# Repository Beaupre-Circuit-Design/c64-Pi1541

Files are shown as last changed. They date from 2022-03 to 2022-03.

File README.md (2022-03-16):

# Pi1541-Hat

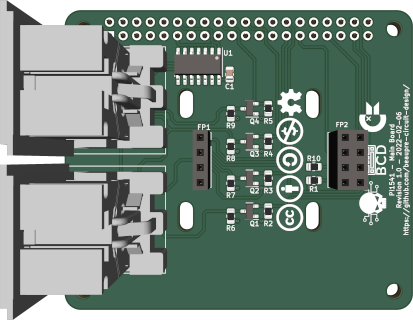
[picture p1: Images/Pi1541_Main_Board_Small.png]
MegaCart-64 Rendering

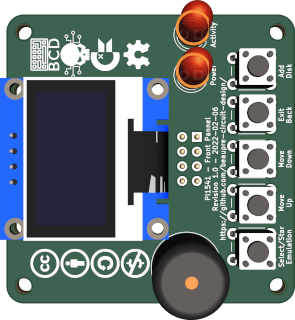
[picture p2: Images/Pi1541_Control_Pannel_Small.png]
MegaCart-64 PCB


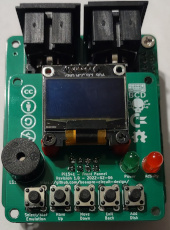
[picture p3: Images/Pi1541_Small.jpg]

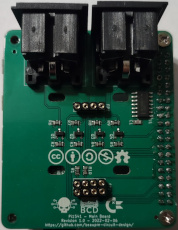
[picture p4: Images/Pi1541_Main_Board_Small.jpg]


# Introduction

An open-source Raspberry-Pi Hat for the [Pi1541 firmware](https://cbm-pi1541.firebaseapp.com/). The Hat is divided into two small PCB, the mainboard with the connectors and support logic, and the control board.  They can be assembled together in one unit, or separatly to fit your choice of enclosure.

# Compatibility

The Hat should be compatible with all 40-pins Raspberry Pi supported by the Pi1541 project. That said, i've only tested it with a Raspberry-Pi Zero 2W.

# Configuration

## Rasperry-Pi Zero/2/3.

Follow the instructions of the official firmware. Once your SD created, change the following lines in the file 'options.txt':

    // Uncomment splitIECLines by uncommenting this line. .
	splitIECLines = 1
	// Enable the LCD Display by uncommenting this line. 
	LCDName = ssd1306_128x64
	// Enable KeyboardBrowseLCDScreen by uncommenting theses lines.
	KeyboardBrowseLCDScreen = 1
	i2cBusMaster = 0
	// Disabling GraphIEC for more stability and compatibility with fastloaders by commenting this line.
	//GraphIEC = 1

## Rasperry-Pi Zero 2W.

Follow the instructions of the [c64-Pi1541-Zero2W-Firmware]([Firmware/](https://github.com/Beaupre-Circuit-Design/c64-Pi1541-Zero2W-Firmware)) Github repository.

# Components and assembly

[Gerbers files](Gerbers/) and SMD assembly files are available for uploading to your prefered manufacturer (I personnally use JLCPCB).  The mainboard use SMT parts (except for the headers) while the control board use through-hole components. Refer to the [Bill of Materials](Pi1541-BOM.xlsx) Excel sheet for a complete list of needed components.

# Licence

This work is licensed under the Creative Commons Attribution-NonCommercial-ShareAlike 4.0 International License. To view a copy of this license, visit http://creativecommons.org/licenses/by-nc-sa/4.0/ or send a letter to Creative Commons, PO Box 1866, Mountain View, CA 94042, USA.

# Revision History

|Revision  |Description |
|:---:|---|
|1.0 |Initial prototype |

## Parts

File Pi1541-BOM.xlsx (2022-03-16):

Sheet: Main Board
Ref | Value | Footprint | Datasheet | Manufacturer | Mfr.Part | LCSC | Digikey | AliExpress | Notes
C1 | 100nF | Capacitor_SMD:C_0805_2012Metric | https://datasheet.lcsc.com/lcsc/1810241824_Samsung-Electro-Mechanics-CL21C101JBANNNC_C1790.pdf | Samsung Electro-Mechanics | CL21C101JBANNNC | C1790 | 1276-1014-1-ND
FP1 | Conn_01x04_Counter_Clockwise | Connector_PinSocket_2.54mm:PinSocket_1x04_P2.54mm_Vertical | https://datasheet.lcsc.com/lcsc/2103011236_BOOMELE-Boom-Precision-Elec-C2718488_C2718488.pdf | Boom Precision Elec | C2718488 | C2718488 | S7037-ND
FP2 | Conn_02x04_Counter_Clockwise | Connector_PinSocket_2.54mm:PinSocket_2x04_P2.54mm_Vertical | https://datasheet.lcsc.com/lcsc/1810221610_Ckmtw-Shenzhen-Cankemeng-B-2200S08P-B120_C124422.pdf | Shenzhen Cankemeng | B-2200S08P-B120 | C124422 | S7107-ND
J1 | DIN-45322 | DIN_45322:DIN_45322 | https://www.aliexpress.com/item/1005001265863686.html | AliExpress |  |  |  | 1005001265863680
J2 | DIN-45322 | DIN_45322:DIN_45322 | https://www.aliexpress.com/item/1005001265863686.html | AliExpress |  |  |  | 1005001265863680
P1 | Conn_02x20_Odd_Even | Connector_PinSocket_2.54mm:PinSocket_2x20_P2.54mm_Vertical | https://datasheet.lcsc.com/lcsc/1811111512_BOOMELE-Boom-Precision-Elec-C50982_C50982.pdf | Boom Precision Elec | C50982 | C50982 | S7123-ND
Q1 | BSS138 | Package_TO_SOT_SMD:SOT-23 | https://datasheet.lcsc.com/lcsc/1811101310_Shikues-BSS138_C112239.pdf | Shikues | BSS138 | C112239 | BSS138CT-ND
Q2 | BSS138 | Package_TO_SOT_SMD:SOT-23 | https://datasheet.lcsc.com/lcsc/1811101310_Shikues-BSS138_C112239.pdf | Shikues | BSS138 | C112239 | BSS138CT-ND
Q3 | BSS138 | Package_TO_SOT_SMD:SOT-23 | https://datasheet.lcsc.com/lcsc/1811101310_Shikues-BSS138_C112239.pdf | Shikues | BSS138 | C112239 | BSS138CT-ND
Q4 | BSS138 | Package_TO_SOT_SMD:SOT-23 | https://datasheet.lcsc.com/lcsc/1811101310_Shikues-BSS138_C112239.pdf | Shikues | BSS138 | C112239 | BSS138CT-ND
R1 | 100Ω | Resistor_SMD:R_0805_2012Metric | https://datasheet.lcsc.com/lcsc/2110251730_UNI-ROYAL-Uniroyal-Elec-0805W8F1000T5E_C17408.pdf | UNI-ROYAL(Uniroyal Elec) | 0805W8F1000T5E | C17408 | 311-100CRCT-ND
R2 | 1KΩ | Resistor_SMD:R_0805_2012Metric | https://datasheet.lcsc.com/lcsc/2110251730_UNI-ROYAL-Uniroyal-Elec-0805W8F1001T5E_C17513.pdf | UNI-ROYAL(Uniroyal Elec) | 0805W8F1001T5E | C17513 | 311-1.00KCRCT-ND
R3 | 1KΩ | Resistor_SMD:R_0805_2012Metric | https://datasheet.lcsc.com/lcsc/2110251730_UNI-ROYAL-Uniroyal-Elec-0805W8F1001T5E_C17513.pdf | UNI-ROYAL(Uniroyal Elec) | 0805W8F1001T5E | C17513 | 311-1.00KCRCT-ND
R4 | 1KΩ | Resistor_SMD:R_0805_2012Metric | https://datasheet.lcsc.com/lcsc/2110251730_UNI-ROYAL-Uniroyal-Elec-0805W8F1001T5E_C17513.pdf | UNI-ROYAL(Uniroyal Elec) | 0805W8F1001T5E | C17513 | 311-1.00KCRCT-ND
R5 | 1KΩ | Resistor_SMD:R_0805_2012Metric | https://datasheet.lcsc.com/lcsc/2110251730_UNI-ROYAL-Uniroyal-Elec-0805W8F1001T5E_C17513.pdf | UNI-ROYAL(Uniroyal Elec) | 0805W8F1001T5E | C17513 | 311-1.00KCRCT-ND
R6 | 1KΩ | Resistor_SMD:R_0805_2012Metric | https://datasheet.lcsc.com/lcsc/2110251730_UNI-ROYAL-Uniroyal-Elec-0805W8F1001T5E_C17513.pdf | UNI-ROYAL(Uniroyal Elec) | 0805W8F1001T5E | C17513 | 311-1.00KCRCT-ND
R7 | 1KΩ | Resistor_SMD:R_0805_2012Metric | https://datasheet.lcsc.com/lcsc/2110251730_UNI-ROYAL-Uniroyal-Elec-0805W8F1001T5E_C17513.pdf | UNI-ROYAL(Uniroyal Elec) | 0805W8F1001T5E | C17513 | 311-1.00KCRCT-ND
R8 | 1KΩ | Resistor_SMD:R_0805_2012Metric | https://datasheet.lcsc.com/lcsc/2110251730_UNI-ROYAL-Uniroyal-Elec-0805W8F1001T5E_C17513.pdf | UNI-ROYAL(Uniroyal Elec) | 0805W8F1001T5E | C17513 | 311-1.00KCRCT-ND
R9 | 1KΩ | Resistor_SMD:R_0805_2012Metric | https://datasheet.lcsc.com/lcsc/2110251730_UNI-ROYAL-Uniroyal-Elec-0805W8F1001T5E_C17513.pdf | UNI-ROYAL(Uniroyal Elec) | 0805W8F1001T5E | C17513 | 311-1.00KCRCT-ND
R10 | 100Ω | Resistor_SMD:R_0805_2012Metric | https://datasheet.lcsc.com/lcsc/2110251730_UNI-ROYAL-Uniroyal-Elec-0805W8F1000T5E_C17408.pdf | UNI-ROYAL(Uniroyal Elec) | 0805W8F1000T5E | C17408 | 311-100CRCT-ND
U1 | 74LS06 | Package_SO:SOIC-14_3.9x8.7mm_P1.27mm | https://datasheet.lcsc.com/lcsc/1810151621_Texas-Instruments-SN74LS06DR_C113682.pdf | Texas Instruments | SN74LS06DR | C113682 | 296-14876-1-ND

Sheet: Front Pannel
Ref | Value | Footprint | Datasheet | Manufacturer | Mfr.Part | LCSC | Digikey | AliExpress | Notes
D1 | RED LED | LED_THT:LED_D5.0mm | https://datasheet.lcsc.com/lcsc/1810271709_Everlight-Elec-333-2SURD-S530-A3_C87271.pdf | Everlight Elec | 333-2SURD/S530-A3 | C87271 | 1125-1188-ND
D2 | GREEN LED | LED_THT:LED_D5.0mm | https://datasheet.lcsc.com/lcsc/1810271709_Everlight-Elec-333-2SURD-S530-A3_C87271.pdf | Everlight Elec | 333-2SYGD/S530-E2 | C88163 | 1125-1184-ND
DS1 | 128x64_I2C_OLED_Display | Display_I2C_OLED:128x64 I2C OLED Display | https://www.aliexpress.com/item/1005001621806398.html | AliExpress |  |  |  | 1005001621806390
FP1 | Conn_01x04_Counter_Clockwise | Connector_PinHeader_2.54mm:PinHeader_1x04_P2.54mm_Vertical | https://datasheet.lcsc.com/lcsc/1811151421_Ckmtw-Shenzhen-Cankemeng-B-2100S04P-A110_C124378.pdf | Shenzhen Cankemeng | B-2100S04P-A110 | C124378 | 609-3305-ND
FP2 | Conn_02x04_Counter_Clockwise | Connector_PinHeader_2.54mm:PinHeader_2x04_P2.54mm_Vertical | https://datasheet.lcsc.com/lcsc/1811151421_Ckmtw-Shenzhen-Cankemeng-B-2100S08P-B110_C124386.pdf | Shenzhen Cankemeng | B-2100S08P-B110 | C124386 | 609-3391-ND
LS1 | YHE12-03 | Buzzer_Beeper:Buzzer_12x9.5RM7.6 | https://www.aliexpress.com/item/33005016402.html | AliExpress |  |  |  | 33005016402
SW1 | SW_Push | Button_Switch_THT:SW_PUSH_6mm | https://www.aliexpress.com/item/32912263133.html | AliExpress |  |  |  | 32912263133
SW2 | SW_Push | Button_Switch_THT:SW_PUSH_6mm | https://www.aliexpress.com/item/32912263133.html | AliExpress |  |  |  | 32912263133
SW3 | SW_Push | Button_Switch_THT:SW_PUSH_6mm | https://www.aliexpress.com/item/32912263133.html | AliExpress |  |  |  | 32912263133
SW4 | SW_Push | Button_Switch_THT:SW_PUSH_6mm | https://www.aliexpress.com/item/32912263133.html | AliExpress |  |  |  | 32912263133
SW5 | SW_Push | Button_Switch_THT:SW_PUSH_6mm | https://www.aliexpress.com/item/32912263133.html | AliExpress |  |  |  | 32912263133

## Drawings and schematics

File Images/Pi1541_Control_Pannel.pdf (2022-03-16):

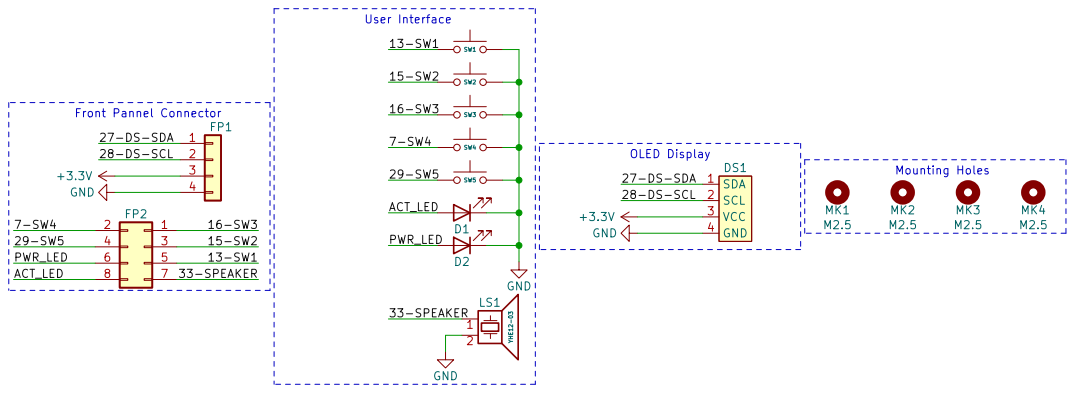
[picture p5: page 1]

OLED Display Front Pannel Connector
27-DS-SDA
28-DS-SCL

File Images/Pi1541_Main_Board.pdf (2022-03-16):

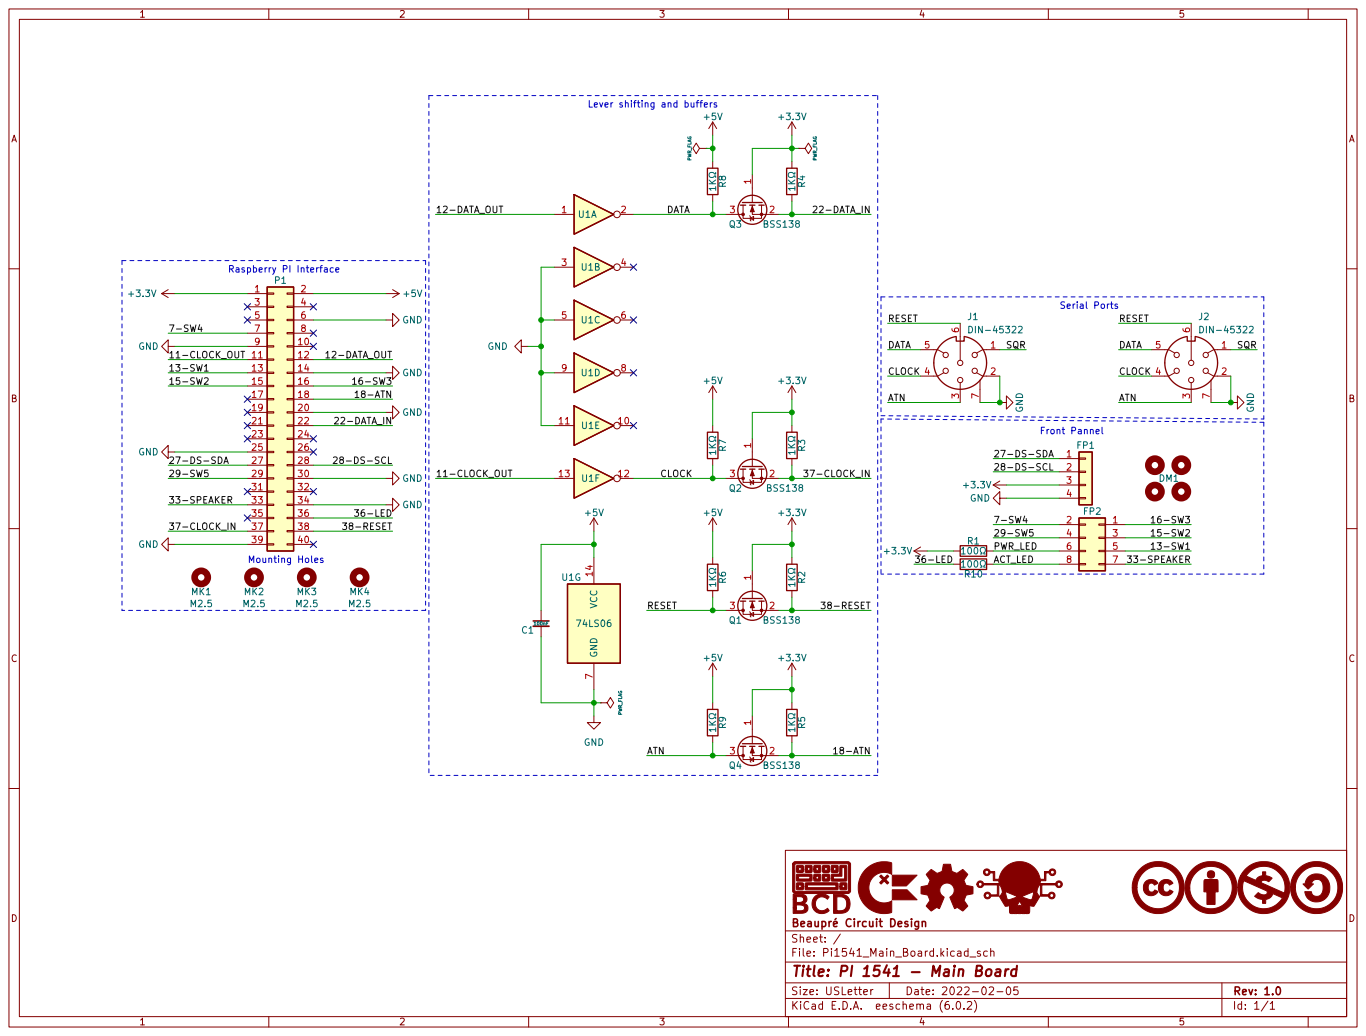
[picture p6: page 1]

Lever shifting and buffers

Id: 1/1 Title: PI 1541 - Main Board

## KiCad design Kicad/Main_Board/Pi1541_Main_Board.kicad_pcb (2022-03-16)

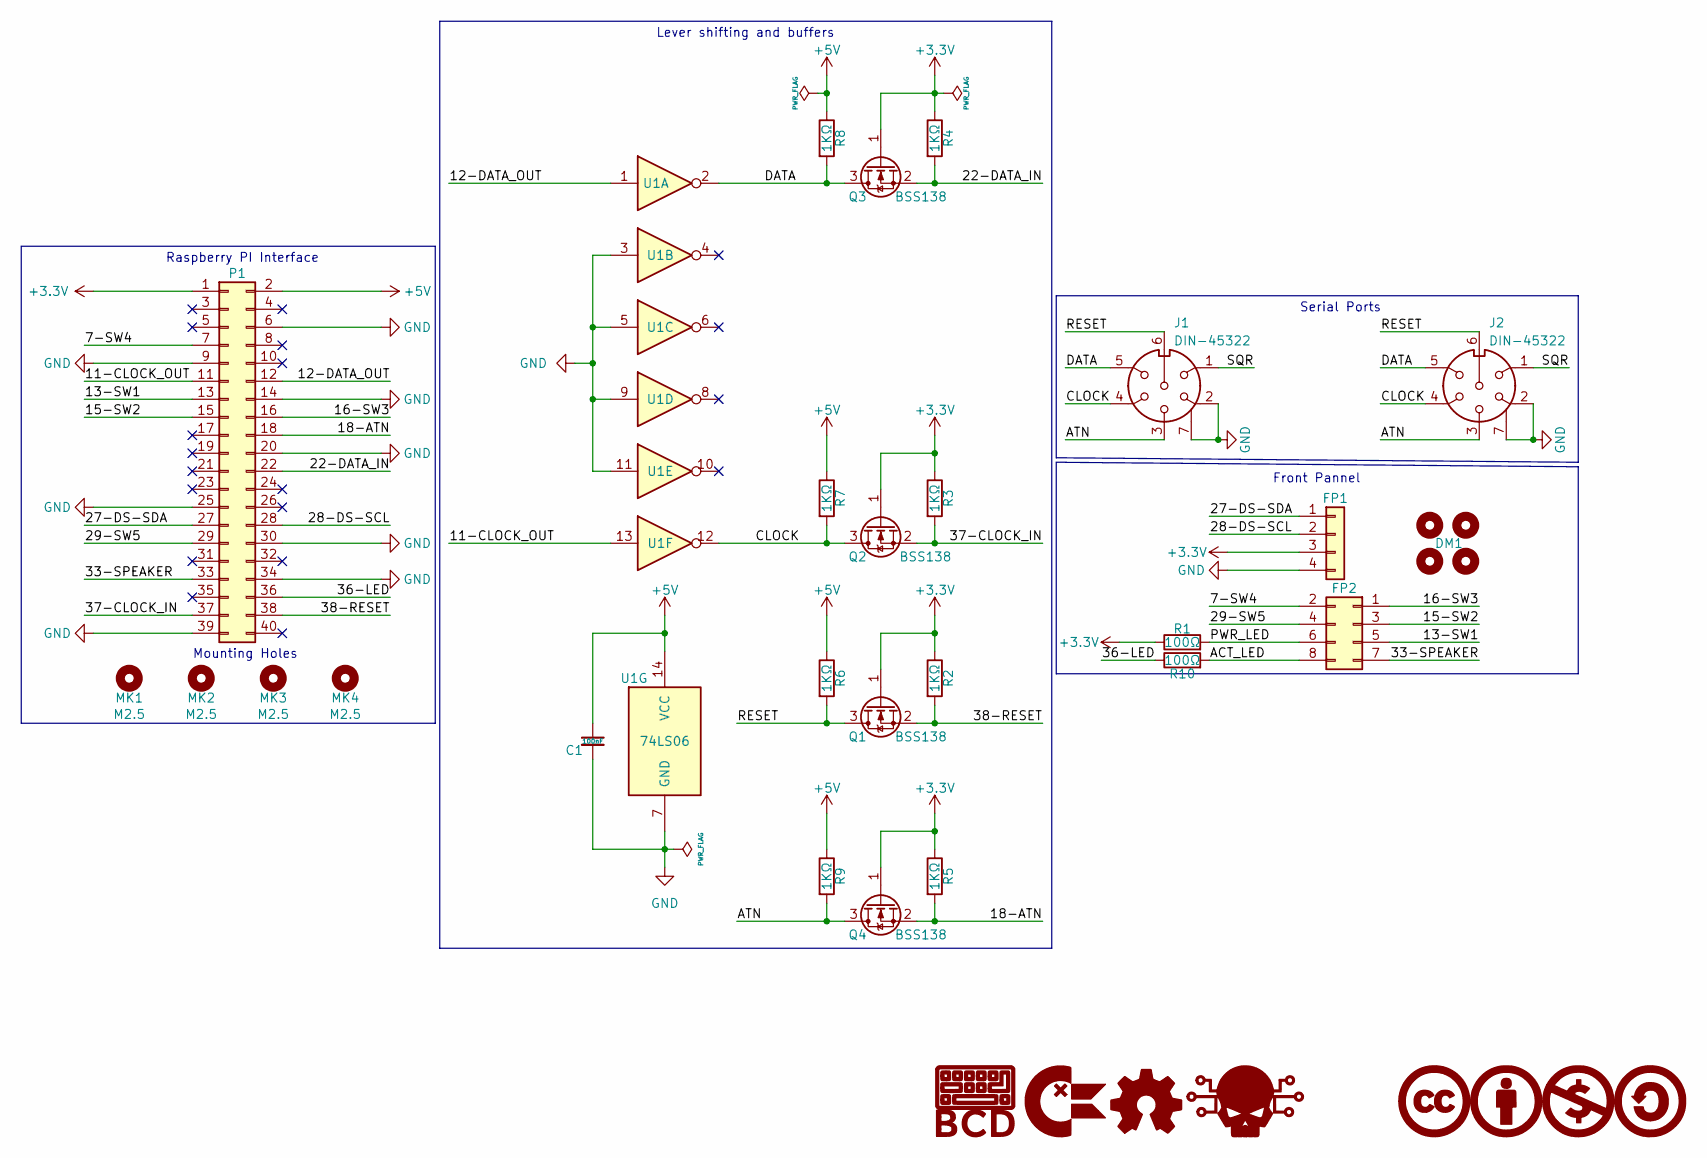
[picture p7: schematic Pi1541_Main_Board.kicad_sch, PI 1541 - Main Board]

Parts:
C1: 100nF; C_0805_2012Metric; Mfr.Part CL21C101JBANNNC; LCSC C1790
DM1: 128x64_I2C_OLED_Mounting_Holes; 128x64 I2C OLED Mounting Holes
FP1: Conn_01x04_Counter_Clockwise; PinSocket_1x04_P2.54mm_Vertical; Mfr.Part C2718488; LCSC C2718488
FP2: Conn_02x04_Counter_Clockwise; PinSocket_2x04_P2.54mm_Vertical; Mfr.Part B-2200S08P-B120; LCSC C124422
G1: BCD_Logo; BCD_Logo_5mm
G2: ChickenLips; ChickenLips_5mm
G3: OpenSource_Hardware; Open_Source_Hardware_5mm
G4: Skull; Skull_5mm
G5: CreativeCommons; CreativeCommons_5mm
G6: CreativeCommons_Attribution; CreativeCommons_Attribution_5mm
G7: CreativeCommons_NonCommercial; CreativeCommons_NonCommercial_5mm
G8: CreativeCommons_ShareAlike; CreativeCommons_ShareAlike_5mm
J1, J2: DIN-45322; DIN_45322
MK1, MK2, MK3, MK4: M2.5; MountingHole_2.7mm_M2.5
P1: Conn_02x20_Odd_Even; PinSocket_2x20_P2.54mm_Vertical; Mfr.Part C50982; LCSC C50982
Q1, Q2, Q3, Q4: BSS138; SOT-23; Mfr.Part BSS138; LCSC C112239
R1, R10: 100Ω; R_0805_2012Metric; Mfr.Part 0805W8F1000T5E; LCSC C17408
R2, R3, R4, R5, R6, R7, R8, R9: 1KΩ; R_0805_2012Metric; Mfr.Part 0805W8F1001T5E; LCSC C17513
U1: 74LS06; SOIC-14_3.9x8.7mm_P1.27mm; Mfr.Part SN74LS06DR; LCSC C113682

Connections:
+3V3: FP1.3, P1.1, Q1.1 (G), Q2.1 (G), Q3.1 (G), Q4.1 (G), R1.1, R2.1, R3.1, R4.1, R5.1
+5V: C1.1, P1.2, R6.1, R7.1, R8.1, R9.1, U1.14 (VCC)
/7-SW4: FP2.2, P1.7
/11-CLOCK_OUT: P1.11, U1.13
/12-DATA_OUT: P1.12, U1.1
/13-SW1: FP2.5, P1.13
/15-SW2: FP2.3, P1.15
/16-SW3: FP2.1, P1.16
/18-ATN: P1.18, Q4.2 (S), R5.2
/22-DATA_IN: P1.22, Q3.2 (S), R4.2
/27-DS-SDA: FP1.1, P1.27
/28-DS-SCL: FP1.2, P1.28
/29-SW5: FP2.4, P1.29
/33-SPEAKER: FP2.7, P1.33
/36-LED: P1.36, R10.1
/37-CLOCK_IN: P1.37, Q2.2 (S), R3.2
/38-RESET: P1.38, Q1.2 (S), R2.2
/ACT_LED: FP2.8, R10.2
/ATN: J1.3, J2.3, Q4.3 (D), R9.2
/CLOCK: J1.4, J2.4, Q2.3 (D), R7.2, U1.12
/DATA: J1.5, J2.5, Q3.3 (D), R8.2, U1.2
/PWR_LED: FP2.6, R1.2
/RESET: J1.6, J2.6, Q1.3 (D), R6.2
/SQR: J1.1, J2.1
GND: C1.2, FP1.4, J1.2, J1.7, J2.2, J2.7, P1.6, P1.9, P1.14, P1.20, P1.25, P1.30, P1.34, P1.39, U1.3, U1.5, U1.7 (GND), U1.9, U1.11

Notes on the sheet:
Front Pannel
Serial Ports
Mounting Holes
Raspberry PI Interface
Lever shifting and buffers

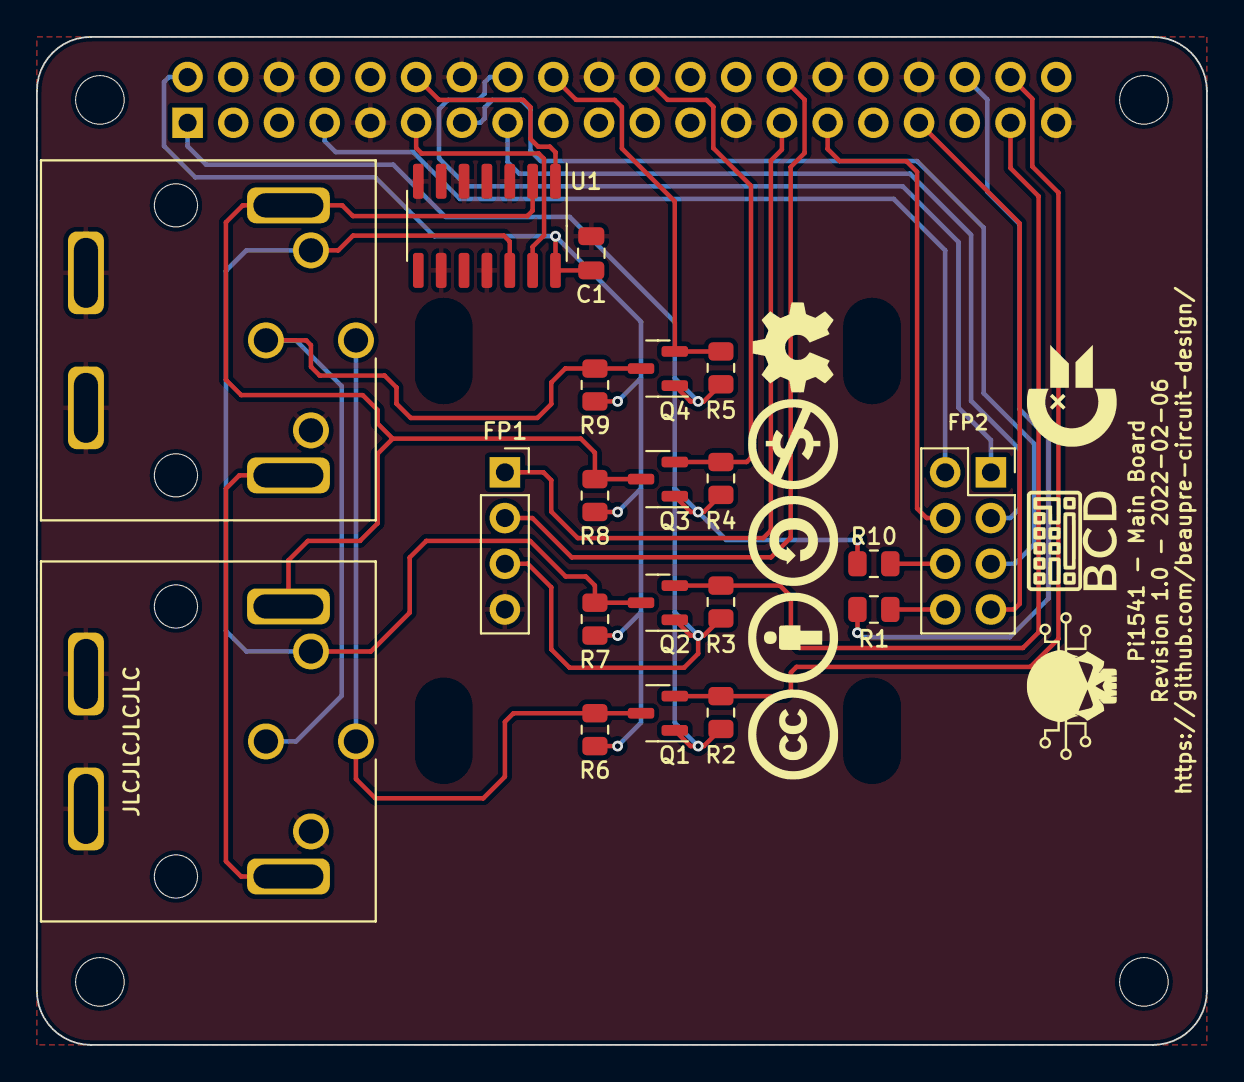
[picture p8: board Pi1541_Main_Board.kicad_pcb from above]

Board: 2 copper layers, 65.0 x 56.0 mm, 34 parts (1 on the bottom side), 25 nets.

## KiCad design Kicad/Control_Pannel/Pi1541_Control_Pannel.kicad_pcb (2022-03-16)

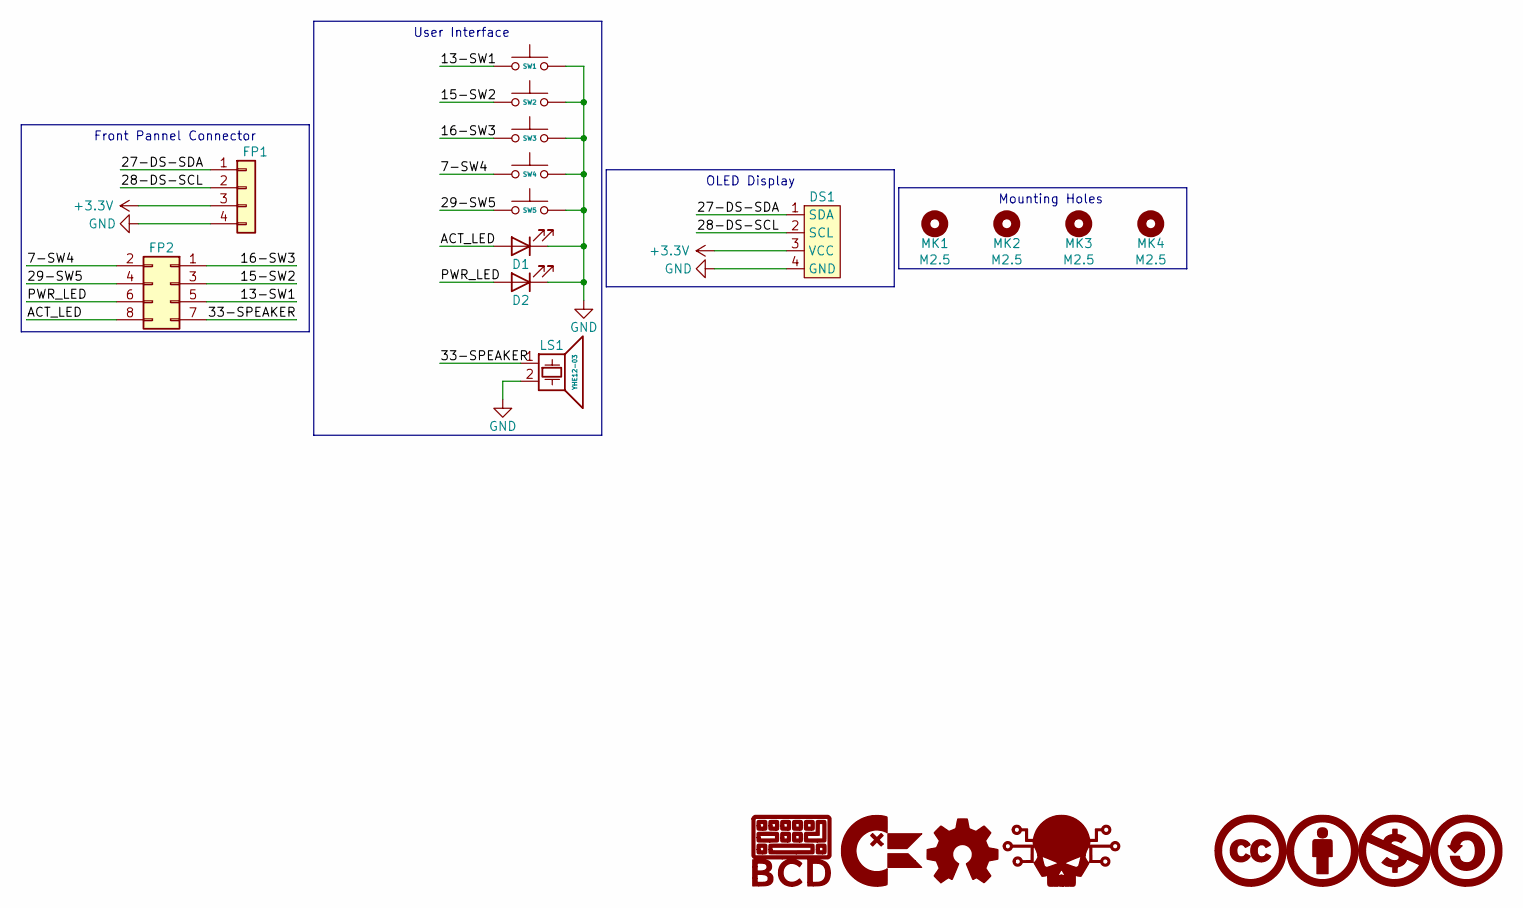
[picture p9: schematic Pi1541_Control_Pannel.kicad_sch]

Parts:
D1: RED LED; LED_D5.0mm; Mfr.Part 333-2SURD/S530-A3; LCSC C87271
D2: GREEN LED; LED_D5.0mm; Mfr.Part 333-2SYGD/S530-E2; LCSC C88163
DS1: 128x64_I2C_OLED_Display; 128x64 I2C OLED Display
FP1: Conn_01x04_Counter_Clockwise; PinHeader_1x04_P2.54mm_Vertical; Mfr.Part B-2100S04P-A110; LCSC C124378
FP2: Conn_02x04_Counter_Clockwise; PinHeader_2x04_P2.54mm_Vertical; Mfr.Part B-2100S08P-B110; LCSC C124386
G1: BCD_Logo; BCD_Logo_5mm
G2: ChickenLips; ChickenLips_5mm
G3: OpenSource_Hardware; Open_Source_Hardware_5mm
G4: Skull; Skull_5mm
G5: CreativeCommons; CreativeCommons_5mm
G6: CreativeCommons_Attribution; CreativeCommons_Attribution_5mm
G7: CreativeCommons_NonCommercial; CreativeCommons_NonCommercial_5mm
G8: CreativeCommons_ShareAlike; CreativeCommons_ShareAlike_5mm
LS1: YHE12-03; Buzzer_12x9.5RM7.6
MK1, MK2, MK3, MK4: M2.5; MountingHole_2.7mm_M2.5
SW1, SW2, SW3, SW4, SW5: SW_Push; SW_PUSH_6mm

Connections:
+3V3: DS1.3 (VCC), FP1.3
/7-SW4: FP2.2, SW4.1
/13-SW1: FP2.5, SW1.1
/15-SW2: FP2.3, SW2.1
/16-SW3: FP2.1, SW3.1
/27-DS-SDA: DS1.1 (SDA), FP1.1
/28-DS-SCL: DS1.2 (SCL), FP1.2
/29-SW5: FP2.4, SW5.1
/33-SPEAKER: FP2.7, LS1.1
/ACT_LED: D1.2 (A), FP2.8
/PWR_LED: D2.2 (A), FP2.6
GND: D1.1 (K), D2.1 (K), DS1.4 (GND), FP1.4, LS1.2, SW1.2, SW2.2, SW3.2, SW4.2, SW5.2

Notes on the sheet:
Front Pannel Connector
Mounting Holes
OLED Display
User Interface

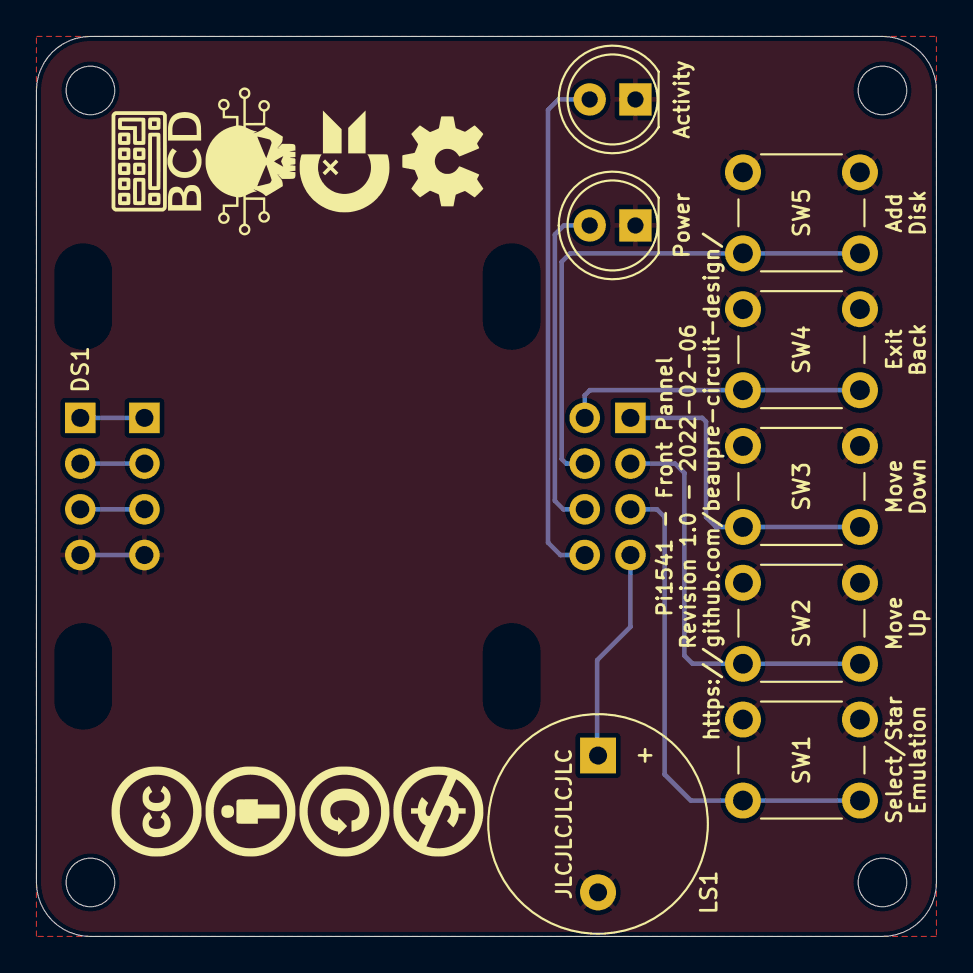
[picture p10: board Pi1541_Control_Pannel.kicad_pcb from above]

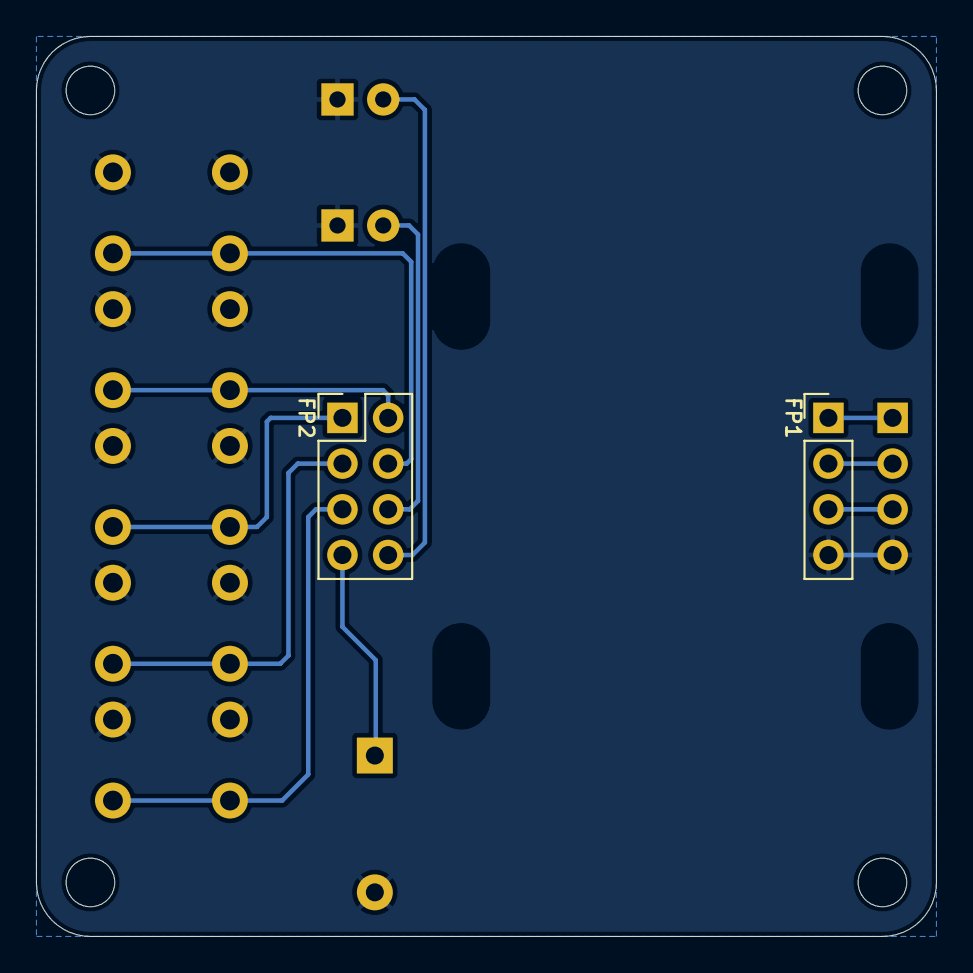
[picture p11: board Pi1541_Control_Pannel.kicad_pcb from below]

Board: 2 copper layers, 50.0 x 50.0 mm, 23 parts (2 on the bottom side), 12 nets.

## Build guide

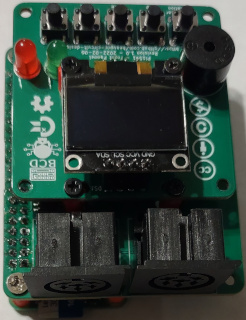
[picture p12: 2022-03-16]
Images/Pi1541_Assembly_Rear_Small.jpg
